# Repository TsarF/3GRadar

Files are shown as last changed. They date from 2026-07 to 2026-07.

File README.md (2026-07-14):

# 3GRadar

Antenna design workspace for a **3.1–3.4 GHz** (9% band) radar front end, targeting
manufacture on **JLCPCB PTFE** (ZYF300CA-C, Dk 2.94, Df 0.0016, 1.52 mm). Electromagnetic
design is done with **openEMS** (FDTD) driven from Python, plus some MATLAB Antenna Toolbox
prototyping and a KiCad project for the RF board.

The current focus is a high-gain **Fabry–Perot cavity (FPC) antenna** — a fed patch under a
partially-reflecting surface (PRS) and a resonant complementary metasurface (RCM), inspired
by Ding et al. (*Results in Engineering* 27, 2025), retuned for the 3.25 GHz band.

> Note: the reference paper PDF and all multi-GB openEMS run outputs are intentionally
> excluded from version control (see `.gitignore`).

## Layout

**Fabry–Perot cavity antenna (active work)**
- `fpc3_build.py` — 3-layer model: inset-fed patch → air cavity → wire-grid PRS → air cavity → subdivided RCM. Env/flag-configurable (`FEED_ONLY`, `RCM_ON`, `MATCH_ON`, …).
- `fpc3_optimize_de_gain.py` — differential-evolution optimizer maximizing **worst-in-band realized gain**, co-tuning feed (y0, L, W) with cavity (h_cav, h3) and RCM sub-spacing (rcm_gap). Full-state checkpointing (resumes after interruption); parallelism is env-configurable.
- `fpc3_validate.py` — high-fidelity full-cavity validation (S11, input Z, directivity, realized gain).
- `fpc3_characterize.py`, `fpc3_impedance.py`, `fpc3_feed_optimize.py`, `fpc3_sweep.py` — diagnostics and feed studies.
- `fpc2_*.py`, `fpc_*.py` — earlier single-PRS and first-cut FPC iterations.
- `fpc_bempp_*.py` — MoM/BEM cross-checks via `bempp-cl`.

**Guides**
- `fpc3_THREADRIPPER.md` — running the optimizer on a many-core box (worker/thread sizing).
- `fpc3_EC2.md` — running it on EC2 M8g **spot** with checkpoint durability (S3 sync / persistent EBS).

**Other antenna studies**
- `inset_slot_*.py`, `inset_patch_build.py`, `series_patch_build.py` — patch feed studies.
- `pcb_*.py`, `array2x2_build.py` — 2×2 PCB array build/optimize.
- `*.m` — MATLAB horn, patch, and matching-network prototyping.

**Board**
- `3GRadar.kicad_*`, `TX.kicad_sch`, `RX.kicad_sch`, `Parts.pretty/` — KiCad RF project.

## Requirements
Python with `openEMS` + `CSXCAD` bindings, `numpy`, `matplotlib` (and `bempp-cl` for the MoM
cross-checks). openEMS must be built for your platform (no ARM64 wheels — see `fpc3_EC2.md`).

## Optimizer quick start
```bash
python fpc3_optimize_de_gain.py                 # local defaults (2 workers x 4 threads)
FPC_WORKERS=16 FPC_THREADS=4 FPC_TAG=_run python fpc3_optimize_de_gain.py   # bigger box
```
It checkpoints the best design to `fpc3_gain_de_opt<TAG>/optimized_params.json` and the full
DE state to `de_state.pkl`; relaunching resumes mid-search.

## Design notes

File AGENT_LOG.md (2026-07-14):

# AGENT_LOG — Autonomous FPC antenna iteration

Agent: Claude (Opus 4.8). Objective: push worst-in-band realized boresight gain
toward ~15 dBi over 3.1–3.4 GHz within a ≤200 mm board. All gain numbers reported
to the user MUST come from FDTD; bempp is trend-screening only.

---

## 2026-07-07 ~16:40 PDT — Takeover / initial status

**Read HANDOFF.md in full.** Understood mission, solvers, gotchas, guardrails.

**Process health (both alive, verified with Get-Process):**
- DE optimizer `fpc3_optimize_de_gain.py` — PID 8928 (python, started 16:22).
- Watchdog `fpc3_watchdog.ps1` — PID 37168 (powershell, started 16:26).
  Heartbeat `watchdog.hb` current (16:36).
- Did NOT start a second optimizer (per guardrail).

**DE state:** freshly started. `optimized_params.json` does NOT exist yet — still on
the initial population (16 members, NP=16), 0 evals logged in `optimization_log.csv`.
Two FDTD workers running (worker_42740 @~17 min, worker_45436 @~17 min), both ringing
down normally (high-Q cavity; energy decaying past -8 dB). Coarse opt mesh (~4M cells),
WORKERS=2 × 4 threads. Objective = worst-in-band realized gain over 3.10–3.40 GHz;
knobs h_cav[42–50], rcm_s[13–20], h3[36–50], y0[5–13]. Converges on stagnation
(3 gens no improvement) or GEN_CAP=100 / MAX_EVALS=600.

**Timeline estimate:** initial population of 16 at ~20–30 min/eval, 2 at a time
≈ 8 batches ≈ 3–4 h just for gen 0, then DE generations. This is a multi-hour/overnight
run. Plan: poll status + logs periodically, do NOT block.

**Machine:** AMD Ryzen 7 5800X3D, 8 cores / 16 logical, 32 GB RAM (10.6 GB free with
the 2 FDTD workers using ~21 GB). Headroom exists for a thread-limited bempp screen.

**Baseline (pre-DE, from HANDOFF):** hand-swept best D=14.5 dBi, realized-gain peak
12.7 dBi at h_cav=45, rcm_s=17, h3=45, y0=9.5. Known weakness: RCM peak is narrow
(single resonance) — gain sags at band edges → worst-in-band is the limiter.

**Plan:**
1. Let the DE run to convergence; validate winner with `fpc3_characterize.py` (fine mesh).
2. In parallel (thread-limited so as not to starve FDTD): bempp-screen the multi-size /
   weaker RCM idea to see if a second resonance flattens the band. bempp = direction only.
3. Only commit FDTD time to bempp-validated directions.

## 2026-07-07 ~16:55 PDT — bempp import OK; multi-size RCM screen launched

- Confirmed bempp_cl 0.4.2 imports (9 s, 2 threads). DE workers healthy: worker_45436
  at -11.5 dB ringdown (TS 34.6k/70k), worker_42740 at -5 dB (TS 30k). Ringdown is slow
  → revised eval estimate ~35–45 min each, so gen 0 (16 evals ÷ 2) ≈ ~5 h.
- Wrote `fpc_bempp_rcm_screen.py` (new): screens the TOP improvement idea from HANDOFF
  §6 — does a MULTI-SIZE RCM (3 interleaved square sizes {14.5,17,19.5} by (i+j)%3,
  PEC-in-air) sag LESS at band edges than a UNIFORM RCM? Runs one process per frequency
  (3.10/3.25/3.40 GHz) so numba compiles k fresh each time. Syntax-checked; fpc3_build
  also syntax-checked (still buildable).
- Launched it in the background at 2 threads (OMP/MKL/NUMBA/OPENBLAS=2) so it does NOT
  starve the priority-1 DE (8-core CPU already saturated by 2×4-thread FDTD). Output →
  `scratch_bempp_rcm_screen.out`. This is SCREENING ONLY (direction, not magnitude).
  Will monitor DE MC/s; if it collapses I kill the screen.

## 2026-07-07 ~17:15 PDT — Restructured bempp screen to ONE process; DE healthy

- Coordinator guidance: bempp's first solve per PROCESS pays a one-time numba/OpenCL
  compile; run the whole variant sweep in ONE process to amortize it. My first version
  was one-process-per-frequency (3 compiles) and its first solve was very slow under
  2-thread contention (only the 3.10 GHz header printed after ~15 min).
- Killed the old screen SURGICALLY (only the python whose cmdline matched
  `fpc_bempp_rcm_screen`; PID 42228) and stopped the driver loop. Verified DE optimizer
  PID 8928 + its two workers (45436, 42740) and watchdog 37168 all still alive.
- DE health throughout: workers held ~98-103 MC/s (no starvation from 2-thread bempp).
  worker_45436 reached -17 dB ringdown (TS 49k/70k) ~28 min in — first evals ~30-40 min.
  Still 0 rows in optimization_log.csv (gen 0 not finished).
- Rewrote `fpc_bempp_rcm_screen.py`: single process, FREQS(3.10/3.25/3.40) outer x
  variants(no-RCM / uniform s=17 / multi{14.5,17,19.5} interleaved) inner. Per-freq RHS
  via `make_rhs(kval)` closure factory (numba freezes k at compile, so a fresh fn per
  freq is needed). Prints a broadside-D-vs-freq trend table + sag(max-min). Syntax OK.
  Relaunched at 2 threads -> `scratch_bempp_rcm_screen.out` (bg task bgsenqhfi).
- Set up a persistent monitor on driver.out/err + watchdog.log for DE milestones
  (task bvfzcac6x): fires on NEW BEST / gen-done / Converged / generation cap /
  BEST 3-layer / Traceback / watchdog restart / WATCHDOG_DONE.

## 2026-07-07 ~17:20 PDT — Validation procedure prepared (read characterize + watchdog)

Read fpc3_characterize.py, fpc3_watchdog.ps1, fpc3_status.py. Key facts for when the
DE converges:
- `fpc3_characterize.py` imports `fpc3_build as p1` and uses its MODULE-LEVEL knobs
  (h_cav, rcm_s, h3, y0 via `_recompute`). It does NOT read optimized_params.json.
  It uses the FINE mesh (fpc3_build mesh_res = .../24) and NrTS=120000, EndCriteria
  1e-4, NFREQ=601, NGAIN=21, THREADS=8. Output -> fpc3_char/openems.log, plots +
  char_data.npz. ~1 hr. `--replot` reuses char_data.npz.
- Watchdog checks the "done" tail (BEST 3-layer DESIGN | Converged (population |
  generation cap) BEFORE the alive-check each 300 s loop, so on clean convergence it
  writes WATCHDOG_DONE and breaks with NO spurious relaunch. => after convergence the
  optimizer process has exited and nothing heavy is running -> safe to run characterize
  (respects "never two heavy FDTD at once").

VALIDATION PLAN (execute on the convergence milestone):
  1. Confirm optimizer PID 8928 exited + WATCHDOG_DONE present (or driver.out shows
     BEST 3-layer). `python fpc3_status.py` to read winner params.
  2. Set winner h_cav/rcm_s/h3/y0 into fpc3_build.py defaults (small, reversible edit;
     harmless to any watchdog relaunch since the DE warm-starts from the JSON, not the
     module defaults). Syntax-check + 3x3 smoke build first.
  3. Launch `python fpc3_characterize.py` detached; poll fpc3_char/openems.log.
  4. Record real worst-in-band S11 + realized gain-vs-freq (this is the FDTD number to
     report to the user).

Now yielding to armed notifications (bempp screen bgsenqhfi completion + DE milestones
bvfzcac6x). Not polling blindly per coordinator guidance.

## 2026-07-08 ~09:26 PDT — Re-engaged (overnight); DE MILESTONE + bempp relaunch

Was dormant overnight — the persistent monitor did NOT reliably wake me (its events
arrived only when I re-engaged). LESSON: treat resumption as self-paced, not
event-driven. Will note a next-action time before each yield.

**DE MILESTONE (verified via fpc3_status.py):** 50 evals, gen 3.
  BEST worst-in-band realized gain = **11.84 dBi**
  params: h_cav=45.5, rcm_s=17.5, h3=49.5, y0=6.6  (fixed L=26.5,W=29.4,sb=16,N=9,P=21.5)
  across band [3.10..3.40] = [12.47, 13.34, 11.84, 11.97, 11.88] dBi  (found at eval 48)
  NEW BEST progression: e1 +6.41 -> e4 +6.56 -> e5 +10.80 -> e35 +11.55 -> e47 +11.84.
  This is a FLAT band (spread ~1.5 dB, worst 11.84) vs the narrow-peak hand baseline
  (D=14.5 / realized peak 12.7 but sagging hard at edges -> low worst-in-band). The DE
  is optimizing exactly the right thing (worst-in-band) and has traded peak for
  flatness. h3=49.5 sits near the top of its [36,50] range and rcm_s=17.5 mid — worth
  noting h3 may want to exceed 50 (bound may be limiting; revisit after convergence).
  DE STILL RUNNING (2 FDTD workers, ~95 MC/s) -> NOT running characterize yet (guardrail).

**bempp screen had DIED** (bg bash task got killed when I went dormant) after ONE data
  point: no-RCM @3.10 GHz -> broadside 6.69 dBi, peak 8.27@38deg, DOF 5743, and that
  single solve took **837 s** (~14 min) under 2-thread contention. Full 3-freq x 3-var
  screen ~= 2 h. RELAUNCHED robustly as a detached hidden OS process via PowerShell
  Start-Process (PID 46968, pidfile bempp_screen.pid, env OMP/MKL/NUMBA/OPENBLAS=2),
  stdout->scratch_bempp_rcm_screen.out, stderr->.err. Verified alive; it is computing
  the 3.10 GHz no-RCM solve now. DE workers still ~95 MC/s alongside it (not starved).

NEXT ACTION (self-paced): check back ~10:15 PDT to confirm the bempp screen passed the
first point (no-RCM@3.10) and ideally has uniform-vs-multi numbers; and re-poll DE
status. Waiting on: (a) bempp screen verdict on multi-size RCM, (b) DE convergence to
trigger FDTD validation of the flat-band winner.

## 2026-07-08 — COORDINATOR NOTE (main): widened h3 bound + restarted DE
Acted on your finding that h3 was pinned at its upper bound (49.5/50) in the 11.84 dBi
best -> the bound was throttling the DE. Edited fpc3_optimize_de_gain.py PARAMS: h3
upper 50 -> 58. Killed old DE (PID 8928 + workers), relaunched cleanly (NEW PID 1440,
driver.pid updated), warm-started from optimized_params.json so the 11.84 flat-band best
is preserved as the seed. New DE now explores h3 up to 58. Watchdog unaffected (reads
driver.pid=1440). On your next self-resume: fpc3_status.py reflects the new PID; keep
monitoring for a new best above 11.84 that uses h3>50, and proceed with your validation
plan on convergence.

## 2026-07-08 — COORDINATOR NOTE (main): match is the bottleneck; added L,W knobs
Read the best design's S11 (live_s11.png): dips only to ~-4.8 dB @3.13 GHz, worst-in-band
~-1.9 dB, NEVER below -10 dB. Yet realized gain is ~12 dBi flat => directivity is
~16-17 dBi (aperture ceiling) and the POOR MATCH is throwing away ~4 dB. So directivity
is maxed; the FEED MATCH is now the bottleneck. Added L[24.5-28.5], W[26.0-33.0] to the
DE knobs (was only y0 for match) so it can center/deepen the S11 dip. Restarted DE:
NEW PID 52208, 6 knobs [h_cav,rcm_s,h3,y0,L,W], warm-started from optimized_params.json
(the 11.84 best). driver.pid updated. Watch for a new best where S11 goes <-10 and
realized gain climbs toward ~15-16. When you validate at convergence, report the S11
too (it's the story).

## 2026-07-09 ~14:45 PDT — NEW FOCUSED TASK: matched-feed design (DE PAUSED)

Coordinator paused DE + watchdog (DE_PAUSED marker 2026-07-09T14:42) so I have the full
8 cores for FDTD. Do NOT relaunch the DE. Best (11.84 dBi) checkpointed & safe. On
re-engage all processes were already stopped. Stopped the stale milestone monitor
bvfzcac6x. Dropped the multi-size bempp screen (moot now; bempp can't model feed Z).

Best design to match (optimized_params.json): h_cav=45.5, rcm_s=17.5, h3=49.5, y0=6.6,
L=26.5, W=29.4. Directivity ~16-17 dBi (aperture ceiling) but S11 only ~-5 dB (never
< -10) -> ~4 dB of realized gain lost. Cavity/RCM maxed; pure feed-impedance problem.

Feed geometry (fpc3_build): inset-fed patch, 50-ohm microstrip feed line Wf=3.89
(≈50 ohm on 1.52mm PTFE eps_r=2.94) from port x_port=-23.25 to x_in=-6.65 (inset depth
y0=6.6, gap g=1.0, Lf=10). Port = z-lumped 50 ohm at outer feed-line end. DE swept y0
(and L,W) but couldn't beat -5 dB => an impedance offset the inset can't null (cavity
detunes feed, gotcha #4). Plan: diagnose Z(f) then add a quarter-wave transformer /
reference-plane shift / stub in the FEED LINE ONLY.

STEP 1: launched `python fpc3_impedance.py` (moderate mesh /22, NRTS 90k, 8 threads)
detached -> stdout fpc3_impedance/run_stdout.log, FDTD fpc3_impedance/openems.log.
Polling. ~30-45 min.

Impedance FDTD verified running cleanly at ~190 MC/s (8 threads, full machine; DE paused).
While it runs, prepared a matching-network calculator (scratchpad/match_design.py):
reads impedance.csv, diagnoses Z at 3.10/3.25/3.40 + min-S11 + X=0 crossings, and
synthesizes microstrip dims on PTFE (eps_r=2.94, h=1.52). Validated: 50 ohm -> W=3.906 mm
(design Wf=3.89 = 50.14 ohm, confirms feed line is 50 ohm); lg/4 ~= 15 mm @3.25 GHz.
Quarter-wave transformer ready: Zt=sqrt(50*R), e.g. R=100->Zt=70.7ohm W~2.2mm,
R=25->Zt=35ohm W~6mm. NEXT: read Z when the run finishes, diagnose, design, implement.

## 2026-07-09 ~15:40 PDT — IMPEDANCE DIAGNOSIS + narrowband match designed & implemented

Baseline impedance run done (2570 s). Full picture (moderate mesh /22):
  f(GHz)  D(dBi)   Z = R + jX (ohm)      S11
  3.10    11.42    4.4  -5.1            -1.52   <- series resonance (X=0), R tiny
  3.25    15.92    38.2 +79.6           -3.38   <- band center, R near 50 but big +X
  3.30    16.39    81.5 +142.8
  3.35    16.45    264.6 +177.4          (peak D)
  3.395   ~16.2    ~365 +0              anti-resonance (X=0), R huge
  3.40    16.02    365.4 -18.4
  Directivity rises MONOTONICALLY toward the cavity anti-resonance (~3.40). In-band R
  swings 4.4 -> 365 ohm (~80x), X up to +191. |Gamma|~0.68 even at the best in-band point
  => broadband match is Bode-Fano IMPOSSIBLE (confirms coordinator). Baseline files saved
  as fpc3_impedance/impedance_baseline.{csv,png}, imp_baseline.npz.

DESIGN FREQ = 3.25 GHz (band center). Chosen over the higher-D points because R=38 is
already closest to 50 (only reactance to null) and D=15.92 is just 0.5 dB below the peak
(16.45), with more usable bandwidth than the extreme anti-resonance (3.395, R=365).

MATCH (offset line + quarter-wave transformer, all-microstrip, no stub/T-junction):
  Load at old port @3.25: Z_L=38+j80, |Gamma|=0.677 @ +56.4 deg.
  1. Extend the 50-ohm feed line OUTWARD by Loff=4.68 mm (reference-plane shift; rotates
     Gamma to the +real axis -> Z=260 ohm real).
  2. Quarter-wave transformer Zt=sqrt(50*260)=114 ohm -> W=0.75 mm, length Lt=15.68 mm
     (lambda_g/4 @3.25). Transforms 260 -> 50 ohm. New port at outer end (x=-43.6 mm).
  Prepended OUTWARD from the old port so the patch/inset/cavity/RCM are untouched and the
  inward load (38+j80) is preserved automatically. Dims from scratchpad/match_design.py.

IMPLEMENTED in fpc3_build.py behind MATCH_ON toggle (default True):
  - new params Loff=4.68, Wt=0.75, Lt=15.68; _recompute now computes x_port (extended
    feed-line end) and x_tr_out (new port); feed_x=x_tr_out when matching.
  - build_antenna adds the transformer box (x_tr_out..x_port, width Wt) + mesh lines at
    x_port/x_tr_out and y=+/-Wt/2. Syntax OK. 3x3 smoke build meshes cleanly. New port
    x=-43.6 is well inside the 9x9 board (+/-96.75 mm).
  - MATCH_ON=False reverts to the original single-port feed (reversible).

VALIDATION: launched fpc3_impedance.py with the matched feed (bg bu30a64tw), ~185 MC/s,
~40 min. Baseline outputs preserved; new run overwrites impedance.{csv,png}/imp_data.npz
= the MATCHED result. Will read S11(3.25), the -10 dB bandwidth, realized gain, and
confirm directivity held. Next self-resume ~16:25 PDT (or on task completion).

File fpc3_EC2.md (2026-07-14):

# Running the FPC co-optimizer on EC2 M8g spot

`fpc3_optimize_de_gain.py` now writes a **full DE-state checkpoint** (population, per-member
costs, generation, RNG state, eval cache, best, history) atomically after *every* eval, and
resumes from it on launch. So a spot reclaim costs at most the few evals in flight — they
re-run as cache-hits. Validated: interrupt → relaunch → `>>> RESUMED ... gen=N` and continue.

## Region
Best **M8g spot price + capacity**: **us-east-2 (Ohio)** or **us-east-1 (N. Virginia)** —
deepest Graviton capacity and typically the cheapest spot. `us-west-2` / `eu-west-1` are
fine alternates. This is a batch job, so latency to you is irrelevant — optimize for price
and interruption rate. Before launching, check **EC2 Console → Spot Requests → Spot
placement score** for `m8g.16xlarge` in your candidate regions/AZs and pick the highest.

## Instance size — match it to the DE, not "biggest"
DE is synchronous: within a generation only **NP** trials can run in parallel (default
`NP=16`). Beyond 16 concurrent evals there's nothing to run until the generation closes. So
the sweet spot evaluates one whole generation at once:

**→ `m8g.16xlarge` (64 vCPU, 256 GiB): `FPC_WORKERS=16 FPC_THREADS=4`.**
One generation = one parallel batch ≈ one eval-time. Graviton4 is 1 vCPU = 1 real core (no
SMT) with DDR5-5600, so 64 vCPU = 64 real cores and the numbers are honest. RAM is a
non-issue (~6.9 M cells ≈ ~2 GB/worker → ~32 GB of 256).

- Want more exploration? `FPC_NP=24` on **`m8g.24xlarge`** (96 vCPU) → `FPC_WORKERS=24 FPC_THREADS=4`.
- **Don't** jump to `m8g.48xlarge` (192 vCPU) with NP=16 — 176 vCPU sit idle. Only worth it
  if you raise NP to ~48 (slower per-gen, more thorough) or run multiple islands.
- openEMS is memory-bandwidth bound; if a single eval is slow, try `FPC_THREADS=4` vs `8`
  with correspondingly fewer workers and keep whichever gives more **evals/hour** (the
  benchmark loop in `fpc3_THREADRIPPER.md` §3 works here too).

## Setup (ARM64 / aarch64)
The AMI must be ARM64 (Amazon Linux 2023 arm64 or Ubuntu 24.04 arm64). openEMS has no ARM
wheels — build once from source and bake an AMI so respawns are instant:
```bash
sudo dnf groupinstall -y "Development Tools" || sudo apt-get install -y build-essential
# deps: cmake, boost, hdf5, CGAL, tinyxml, vtk, qt; then build openEMS + python bindings
#   https://docs.openems.de/install/  (build AppCSXCAD/CSXCAD/openEMS, pip install its python/)
python -c "import fpc3_build, openEMS, CSXCAD; print('ok')"   # must pass
```
Bake this into a custom AMI so a reclaimed-then-relaunched spot boots ready.

## Spot fault tolerance — durable checkpoint
The checkpoint file must **survive instance termination**. Two options:

**A) S3 sync (recommended — survives full instance loss).** Give the instance an IAM role
with access to a bucket, then run a background sync alongside the optimizer:
```bash
export FPC_CKPT=/data/fpc/de_state.pkl        # local path the optimizer writes
mkdir -p /data/fpc
aws s3 cp s3://YOUR_BUCKET/fpc/de_state.pkl "$FPC_CKPT" 2>/dev/null || true   # restore if exists
# push checkpoint + best to S3 every 60s in the background:
( while true; do
    aws s3 cp "$FPC_CKPT" s3://YOUR_BUCKET/fpc/de_state.pkl --only-show-errors || true
    aws s3 cp fpc3_gain_de_opt_EC2/optimized_params.json s3://YOUR_BUCKET/fpc/ --only-show-errors || true
    sleep 60
  done ) &
```
On a fresh instance the `aws s3 cp ... "$FPC_CKPT"` restore line pulls the latest state and
the optimizer resumes. (Checkpoint is <1 MB, so 60 s sync is cheap. Optionally also trigger
a sync on the 2-min interruption notice — poll
`http://169.254.169.254/latest/meta-data/spot/instance-action`.)

**B) Persistent EBS.** Put the repo + `FPC_CKPT` on a data EBS volume with
`DeleteOnTermination=false`; after a reclaim, launch a new spot, attach the volume, relaunch.

**Auto-relaunch:** request a **persistent** spot request (not one-time) with interruption
behavior `stop` or `terminate`; it re-provisions when capacity returns. Put the launch
command (below) in user-data so a respawn restores from S3 and continues unattended.

## Launch (detached, resumable)
```bash
cd /path/to/3GRadar
# seed the island from your current global best (first launch only):
mkdir -p fpc3_gain_de_opt_EC2
aws s3 cp s3://YOUR_BUCKET/fpc/optimized_params.json fpc3_gain_de_opt_EC2/ 2>/dev/null \
  || cp fpc3_gain_de_opt/optimized_params.json fpc3_gain_de_opt_EC2/ 2>/dev/null || true

FPC_WORKERS=16 FPC_THREADS=4 FPC_TAG=_EC2 FPC_SEED=2025 \
FPC_CKPT=/data/fpc/de_state.pkl \
  nohup python fpc3_optimize_de_gain.py > fpc3_gain_de_opt_EC2/driver.out 2>&1 &
echo $! > fpc3_gain_de_opt_EC2/driver.pid
tail -f fpc3_gain_de_opt_EC2/driver.out
```
If reclaimed and relaunched with the **same env**, it prints `>>> RESUMED ... gen=N` and
continues. `FPC_TAG=_EC2` keeps it isolated from the local run so nothing clobbers.

## Cost sanity
`m8g.16xlarge` on-demand ≈ small-single-digit $/hr; spot typically ~60-70% off. If the
search needs ~20 generations and a generation ≈ one eval-time, budget by benchmarking one
eval on the instance first (`evals/hour` loop) — you'll know $/run before committing.

## Take the winner back
Copy `fpc3_gain_de_opt_EC2/optimized_params.json` (or the S3 copy) into the repo, compare
`worst_realized_gain_dBi` against the local/TR bests, set the winner into `fpc3_build.py`,
and validate at full fidelity: `python fpc3_validate.py`.
```

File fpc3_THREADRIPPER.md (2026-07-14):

# Running the FPC co-optimizer on the Threadripper 7960X

The optimizer (`fpc3_optimize_de_gain.py`) is one script, env-configurable. On the big box
you run it as an **independent island**: its own output dir (`FPC_TAG=_TR`), warm-started
from the current global best, a different `FPC_SEED` so it explores different trials. Both
machines use the *same geometry + mesh (/16)*, so the two `optimized_params.json` are
directly comparable — at the end you keep whichever design has the higher worst-in-band
realized gain. The local run is untouched (defaults preserve 2 workers × 4 threads).

## Why these worker/thread numbers
openEMS FDTD is **memory-bandwidth bound** — a single sim stops scaling past ~6-8 threads.
Throughput on many cores comes from running **more parallel workers**, not fatter sims.
The 7960X has 24 cores across **4 CCDs of 6 cores** (quad-channel DDR5). So:

| Config | env | notes |
|---|---|---|
| **4×6 (start here)**| `FPC_WORKERS=4 FPC_THREADS=6` | one worker per CCD — cache/NUMA-local |
| 6×4 | `FPC_WORKERS=6 FPC_THREADS=4` | more parallel evals, crosses CCDs  |
| 8×3 | `FPC_WORKERS=8 FPC_THREADS=3` | max parallelism; may saturate DRAM BW |

RAM: ~6.9 M cells/worker ≈ ~2 GB/worker → even 8 workers ≈ 16 GB. Not the limiter.
**Benchmark before committing** (see below) — pick the config with the best *evals/hour*,
which is workers ÷ median-eval-time, not just the most workers.

## 1. Get the repo + deps on the TR
Copy the whole `3GRadar` folder over **including** `fpc3_gain_de_opt/optimized_params.json`
(that's the seed). Install openEMS with Python bindings (`openEMS`, `CSXCAD` importable),
plus `numpy`, `matplotlib`.

Quick check the model builds there:
```bash
python -c "import fpc3_build, openEMS, CSXCAD; print('ok')"
```

## 2. Seed the island from the current global best
```bash
# Linux/macOS
mkdir -p fpc3_gain_de_opt_TR
cp fpc3_gain_de_opt/optimized_params.json fpc3_gain_de_opt_TR/optimized_params.json
```
```powershell
# Windows PowerShell
New-Item -ItemType Directory -Force fpc3_gain_de_opt_TR | Out-Null
Copy-Item fpc3_gain_de_opt\optimized_params.json fpc3_gain_de_opt_TR\optimized_params.json
```
(Alternatively skip the copy and point `FPC_WARM` at the local best directly.)

## 3. Benchmark one eval per config (optional, ~15 min, recommended)
Times a single full-cavity eval so you can compare evals/hour:
```bash
for W in "4 6" "6 4" "8 3"; do set -- $W; \
  echo "=== $1 workers x $2 threads ==="; \
  FPC_WORKERS=$1 FPC_THREADS=$2 FPC_TAG=_bench FPC_NP=$1 python - <<'PY'
import os,time,fpc3_optimize_de_gain as o
from concurrent.futures import ProcessPoolExecutor
x=o.snap(o.np.array([o.PARAMS[n][0] for n in o.names]))
t=time.time()
with ProcessPoolExecutor(max_workers=o.WORKERS) as ex:
    list(ex.map(o.eval_worker,[(x,os.path.join(o.sim_path,'b%d'%i),o.THREADS_PER_WORKER) for i in range(o.WORKERS)]))
dt=time.time()-t
print("  %d evals in %.0fs -> %.1f evals/hour"%(o.WORKERS,dt,o.WORKERS*3600/dt))
PY
done; rm -rf fpc3_gain_de_opt_bench
```
Keep the config with the highest evals/hour.

## 4. Launch the island (detached)
```bash
# Linux/macOS — replace 4 6 with your benchmark winner
FPC_WORKERS=4 FPC_THREADS=6 FPC_TAG=_TR FPC_SEED=777 \
  nohup python fpc3_optimize_de_gain.py > fpc3_gain_de_opt_TR/driver.out 2>&1 &
echo $! > fpc3_gain_de_opt_TR/driver.pid
```
```powershell
# Windows PowerShell
$env:FPC_WORKERS=4; $env:FPC_THREADS=6; $env:FPC_TAG='_TR'; $env:FPC_SEED=777
$p = Start-Process python 'fpc3_optimize_de_gain.py' -WindowStyle Hidden -PassThru `
  -RedirectStandardOutput fpc3_gain_de_opt_TR\driver.out -RedirectStandardError fpc3_gain_de_opt_TR\driver.err
$p.Id | Out-File -Encoding utf8 fpc3_gain_de_opt_TR\driver.pid
```

Watch progress:
```bash
tail -f fpc3_gain_de_opt_TR/driver.out          # new-bests + gen summaries
cat  fpc3_gain_de_opt_TR/optimized_params.json  # current best (checkpointed live)
```

## 5. Take the winner back
When done (or when you return the TR), copy `fpc3_gain_de_opt_TR/optimized_params.json`
back into the repo. Compare `worst_realized_gain_dBi` between it and the local
`fpc3_gain_de_opt/optimized_params.json`; set the better design's params into
`fpc3_build.py` and validate at full fidelity with `python fpc3_validate.py`.

**Crash-safe:** the island checkpoints its best every improvement and warm-starts from it,
so if the process dies just relaunch step 4 — no progress lost.

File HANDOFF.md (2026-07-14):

# Antenna Design — Autonomous Handoff Manifest

You are a Claude instance taking over an antenna-design project to **iterate on it
autonomously**. Read this whole file first. It is your single source of truth.

---

## 1. Mission

Design a **high-gain Fabry–Perot cavity (FPC) antenna** for **3.1–3.4 GHz** (9 %
band) on the JLCPCB **PTFE ZYF300CA-C** stack (Dk 2.94, Df 0.0016, 1.52 mm boards),
board side **≤ ~200 mm**. **Objective: maximize the worst-in-band realized boresight
gain** `G = D_broadside · η_rad · (1 − |S11|²)` over 3.10–3.40 GHz.

Practical ceiling at 194 mm (2.1 λ) aperture is **~15 dBi** (the source paper hit 14.9
at this electrical size). 17 dBi is not physical here without a bigger board.

---

## 2. Current state (READ `python fpc3_status.py` FIRST)

- **Best design so far:** the 3-layer antenna `fpc3_build.py` (feed patch + dual-layer
  PRS + RCM superstrate). Hand-swept best: **D = 14.5 dBi, peak realized gain 12.7 dBi**
  at `h_cav=45, rcm_s=17, h3=45, y0=9.5`.
- **A DE optimizer is ALREADY RUNNING** (`fpc3_optimize_de_gain.py`, detached, PID in
  `fpc3_gain_de_opt/driver.pid`) under a **watchdog** (`fpc3_watchdog.ps1`, PID in
  `watchdog.pid`) that relaunches it if it dies. **Do NOT start a second optimizer** —
  check `fpc3_status.py` and the watchdog first.
- It checkpoints the best to `fpc3_gain_de_opt/optimized_params.json` on every
  improvement and logs every eval to `optimization_log.csv`. Warm-starts from the JSON,
  so nothing is lost across restarts.

---

## 3. Environment & solvers

- **Windows, Python 3.13, NVIDIA RTX 4070.** PowerShell is primary; a bash tool exists.
- **openEMS (FDTD), Python bindings** — the accurate solver (has the dielectric). SLOW
  for this high-Q cavity: ~20–30 min/eval at coarse mesh (`mesh_res /20`, ~4 M cells),
  ~1 hr at fine mesh. **This is the source of truth for final numbers.**
- **bempp-cl (MoM, installed as `bempp_cl`)** — fast (~3 min/solve) but **PEC-in-air**
  (ignores the PTFE), so it **undershoots absolute gain by ~3 dB and its optimum spacings
  are ~0.83× the FDTD ones**. CPU only (GPU gives NO speedup — measured). **Use bempp
  ONLY to screen trends/direction cheaply, then validate in FDTD.**
- openEMS output is fd-redirected to per-run logs so it doesn't spam stdout.

---

## 4. File inventory

Active FPC design (use these):
- `fpc3_build.py` — the 3-layer antenna. Knobs: `h_cav, rcm_s, h3, y0` (+ fixed
  `L=26.5, W=29.4, sb=16, r1=6.5, pb=20.7, P=21.5, N_PRS=9`). `RCM_ON` toggles the RCM.
- `fpc3_optimize_de_gain.py` — the running DE (objective = worst-in-band realized gain).
- `fpc3_characterize.py` — full validation: S11 + gain-vs-freq + directivity + E/H
  patterns. `--replot` reuses saved data. ~1 hr (fine mesh).
- `fpc3_sweep.py` — lean N-point FDTD sweep (edit `POINTS`), coarse mesh.
- `fpc3_watchdog.ps1` — keeps the optimizer alive.
- `fpc3_status.py` — one-shot status.
- `fpc_bempp_directivity.py` — bempp MoM directivity screen (edit the sweep in `main()`).

Baselines / building blocks:
- `fpc2_build.py`, `fpc2_characterize.py` — single-PRS FPC (~11 dBi, matched). `FEED_ONLY`
  flag builds just the bare patch.
- `fpc2_prs_unitcell.py` — dual-layer PRS reflection extractor (|Γ|, phase, Trentini
  cavity height) via a TEM waveguide unit cell.
- `fpc2_feed_optimize.py` — Stage-A bare-patch match optimizer (fast, feed-only).
- Older experiments (context only): `fpc_build.py`, `series_patch_build.py`,
  `inset_slot_*`, `inset_patch_*`, `pcb_*`, `part2_simulate.py`.
- `fpc_metasurface paper.pdf` — the source paper (Ding et al., Results in Eng. 27
  (2025) 106647). 3-layer metasurface FPC at 7 GHz; we scaled ×2.15 to 3.25 GHz and
  dropped the CBM (RCS) layer.

---

## 5. Hard-won facts & gotchas (do not relearn these)

1. **Aperture caps gain:** uniform 9×9 (194 mm) → 17.4 dBi ideal, ~15 realized. Bigger
   board needed for more (11×11 ≈ 236 mm → ~17), but user capped ~200 mm.
2. **openEMS drops zero-height cylinders** as "Unused primitive" → build flat discs with
   `AddPolygon` (see `_disc` in the builds). Never use a degenerate `AddCylinder`.
3. **A bare patch can't match across 9 %** (patch BW ~3 %). Match it at BAND CENTER
   (3.25 GHz); the cavity provides band coverage. (Objective for the *feed alone* is S11
   at f0, NOT worst-in-band.)
4. **Adding a superstrate layer detunes the feed** → must re-tune `y0` (and `h_cav`)
   jointly. The RCM's first naive placement killed the match (S11 ≈ 0).
5. **RCM works:** a uniform square-patch RCM adds **+3–5 dB** broadside at `rcm_s≈17,
   h3≈45` — but it's a **single resonance → narrow band** (gain peaks tall, sags at band
   edges). The paper uses THREE varied square sizes to get bandwidth; we haven't.
6. **High-Q ⇒ slow FDTD** (long ringdown). Use `WORKERS=2` (4 thrashes RAM), coarse mesh
   for optimization, fine mesh only for final validation.
7. **bempp PEC-in-air is qualitative only** — screens direction, not magnitude. Its
   optimum ≠ FDTD's. Confirmed it undershoots (single-PRS: bempp 8 vs FDTD 11 dBi).
8. **DE loop bug (fixed):** the loop must terminate on stagnation + a generation cap,
   else it spins forever once the population caches out. Preserve this in any new DE.

---

## 6. Your objective & how to iterate

**Goal:** push worst-in-band realized gain as high as possible (target ~15 dBi) within
≤200 mm, keeping a usable in-band gain floor (not just a tall narrow peak).

**Loop:**
1. `python fpc3_status.py` — see best-so-far, eval count, process health.
2. Verify the optimizer + watchdog are alive (`Get-Process -Id <pid>`). If dead and not
   converged, relaunch the optimizer detached (Start-Process, WorkingDirectory the repo,
   `python fpc3_optimize_de_gain.py`, redirect to `fpc3_gain_de_opt/driver.out`/`.err`,
   hidden, PassThru; write new PID to `driver.pid`). It warm-starts — no loss.
3. When the DE converges (driver.out shows "Converged"/"BEST 3-layer"/"generation cap",
   or a `WATCHDOG_DONE` file appears), run `python fpc3_characterize.py` to VALIDATE the
   winner at fine mesh, and record the real S11 + gain-vs-freq.
4. Then pursue the next improvement (below), using **bempp to screen cheaply first**,
   then **1–2 FDTD validation runs** at the bempp-scaled point. Never blind-grid FDTD.
5. Append everything you do/find/decide to `AGENT_LOG.md` (create it) with timestamps.

**Improvement ideas (in rough priority):**
- **Bandwidth (biggest gap):** the RCM peak is narrow. Try (a) a *weaker* RCM (smaller
  `rcm_s` / bigger `sb`) trading peak for a flatter band, and/or (b) a **multi-size RCM**
  (two or three square sizes per super-cell, like the paper) to add a second resonance
  and flatten gain across 3.1–3.4. This likely needs a new `rcm` build variant.
- **Joint feed re-match** with the RCM present (`y0`, maybe `L`) so realized gain isn't
  killed by mismatch at band edges.
- **PRS reflectivity** (`sb`, `r1`) re-tune for the compound two-layer cavity.
- If the user later relaxes the size cap: 11×11 (236 mm) → ~17 dBi ceiling.

---

## 7. Guardrails (respect these)

- **Never run `WORKERS > 2`** and **never run two heavy FDTD jobs at once** (RAM). One
  optimizer + at most one manual FDTD run.
- **Never delete** `fpc3_gain_de_opt/optimized_params.json` or `optimization_log.csv`.
- **bempp = screening only.** Any gain number you report to the user must come from FDTD.
- Keep the board ≤ ~200 mm and the stack PTFE (Dk 2.94) unless the user says otherwise.
- Checkpoint/log continuously. Prefer small, reversible changes; keep `fpc3_build.py`
  buildable at all times (syntax-check + a 3×3 smoke build before any long run).
- Don't fabricate progress. If a run fails or is inconclusive, say so in `AGENT_LOG.md`.

---

## 8. Quick commands

```
python fpc3_status.py                      # status + best-so-far
python fpc3_characterize.py                # full FDTD validation (~1 hr)
python fpc3_characterize.py --replot       # replot last validation
python fpc_bempp_directivity.py            # bempp trend screen (~3 min/point, edit main)
python -c "import ast; ast.parse(open('fpc3_build.py').read())"   # syntax check
```

Best design lives in `fpc3_gain_de_opt/optimized_params.json`. When in doubt, prefer
watching the running DE to converge over starting new work.

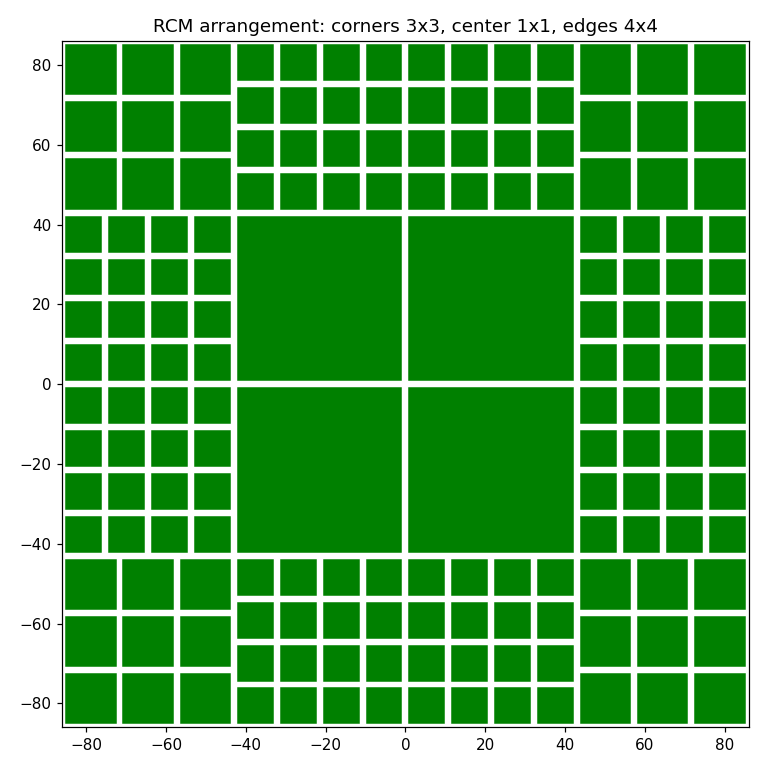
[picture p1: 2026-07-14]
rcm_topview.png

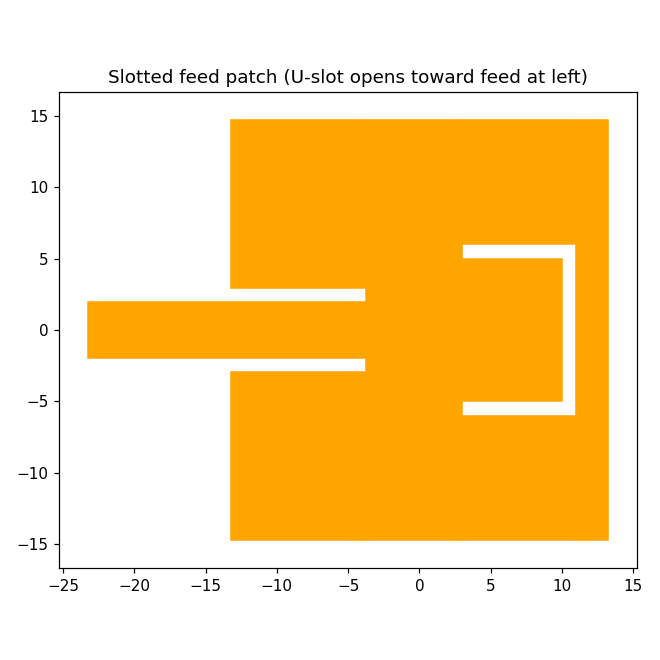
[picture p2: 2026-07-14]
feed_slot_topview.png

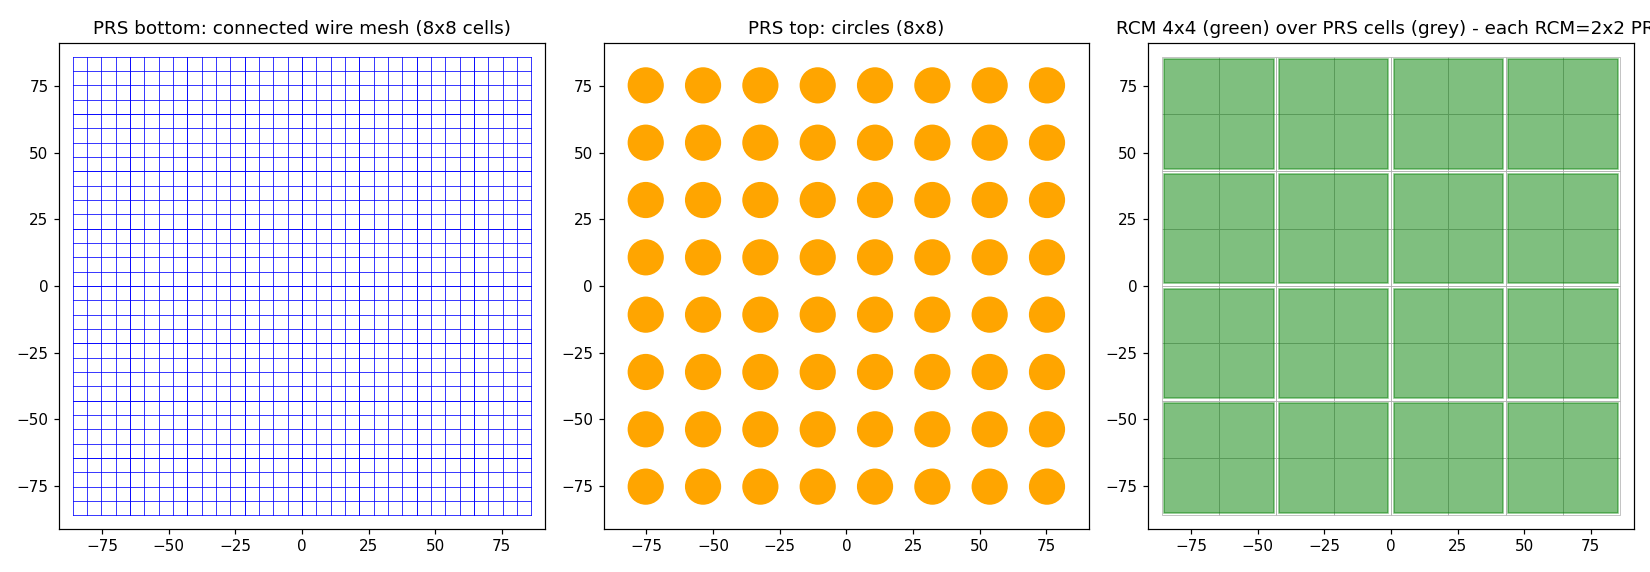
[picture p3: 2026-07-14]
geometry_topview.png

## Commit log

2026-07-14 Initial commit: 3.1-3.4 GHz radar antenna design workspace
    openEMS/Python + MATLAB antenna design for a 3.1-3.4 GHz radar front end on
    JLCPCB PTFE, centered on a Fabry-Perot cavity (FPC) antenna with a wire-grid PRS
    and subdivided RCM. Includes the DE realized-gain co-optimizer (checkpointed,
    env-configurable for multi-machine / EC2 spot), validation/diagnostics, earlier
    patch-array iterations, and the KiCad RF project.
    Reference paper PDF and multi-GB openEMS run outputs are excluded via .gitignore.
    [3GRadar.kicad_pcb, 3GRadar.kicad_sch, RX.kicad_sch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]
2026-07-14 Bake current DE best into fpc3_build defaults (warm-start seed)
    Set h_cav=52, h3=51, rcm_gap=5.5, y0=5.0, L=24.5, W=30.8 -- the 6-knob
    feed+cavity realized-gain DE best so far (worst-in-band +9.40 dBi over 3.1-3.4).
    These defaults are the optimizer's warm-start seed when no de_state/JSON exists,
    so a fresh EC2 clone resumes from this design without an SCP of the checkpoint.
2026-07-14 Fix timestep-cap truncation: PML on all sides + raise NRTS to 150k
    ~82% of evals were hitting the 70k NrTS cap without ringing down to the -30 dB
    EndCriteria -- a parallel-plate mode trapped between the big PEC planes reflected
    off the MUR side walls, so domain energy plateaued and S11/gain were computed on
    an unsettled (truncated) record. Switch all 6 boundaries to PML_8 to absorb that
    mode; raise NRTS to 150k as a safety ceiling (most evals now hit EndCriteria near
    ~77k). Add NRTS+bc to the checkpoint signature so stale truncated caches are not
    resumed. Same fix applied to fpc3_validate.py.
2026-07-14 Model copper as finite-conductivity sheets (not PEC)
    Investigating why some evals still hit the 150k NrTS cap short of -30 dB: with
    lossless PEC metal, the air-filled cavity between the big plates has near-infinite
    conductor Q, so high-Q (narrowband) designs ring essentially forever. Good/broadband
    designs already converge (~130k -> -30 dB, verified), but PEC also overestimates
    realized gain. Switch gnd/patch/PRS/RCM to AddConductingSheet (Cu, 5.8e7 S/m, 35 um):
    realistic loss, de-biased gain, and a bounded cavity Q -> faster ring-down. Add
    metal type to the checkpoint signature so stale PEC-fitness caches are not resumed.
2026-07-16 Harden realized-gain objective: dense match + non-convergence guard
    The EC2 run reported ~17 dBi worst-in-band realized gain with a uniformly ~-5 dB
    in-band S11 -- physically impossible, since 17 dBi exceeds the ~16.4 dBi directivity
    ceiling of the 172 mm aperture. Root cause: high-Q designs that don't ring down to
    the -30 dB EndCriteria within the NrTS cap get their NF2FF directivity computed on
    unsettled fields -> inflated (super-directivity artifact), and a bad match doesn't
    show up because gain was only sampled at NGAIN points.
    Two fixes:
    * Objective now uses worst-in-band realized gain on the DENSE |S11| grid (interp
    directivity/eta_rad, dense match term) so it can't be gamed by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
2026-07-16 Add mesh-convergence check (search-mesh fidelity vs speed)
    The 0.083 mm metal-edge cells Courant-limit the timestep to ~2e-13 s (~1200
    steps/RF-period; Nyquist needs ~2), which is why each eval takes ~3 h -- those
    cells are 3-4x finer than the 0.6 mm PRS wire needs. This runs one design at a
    fine TRUTH mesh vs candidate coarse meshes (edge 0.8/1.0/1.2, min_cell 0.15-0.25)
    in parallel and compares worst-in-band realized gain + |S11|. Adopt the coarsest
    mesh within ~0.3 dB of TRUTH as the search fidelity -> ~3-4x faster EC2 search.
2026-07-16 Make mesh-convergence div22 truth optional (FPC_TRUTH=1)
    Default reference is now the current div16/edge0.4 search mesh -- the mesh we're
    deciding whether to coarsen from -- so the run is gated by ~5.6M cells (~2-3 h on
    m8g) instead of the ~12M div22 mesh (~4-8 h). FPC_TRUTH=1 adds div22 back to also
    confirm div16 is itself converged.
2026-07-17 Add soft match penalty + re-enable U-slot as DE knobs
    The realized-gain objective barely punishes a bad match (a -5 dB match costs only
    1.65 dB of gain), so the DE kept landing on high-directivity/bad-match designs, and
    nothing on EC2 got below -8 dB S11. A hard S11<-10 floor would flatten the objective
    (nothing satisfies it yet) and stall the search, so instead:
    * SOFT graded penalty: score = worst-in-band realized gain
    - MATCH_K*max(0, worstS11 - (-10 dB)) [MATCH_K=1]
    Always gives a gradient; switches off once a design crosses -10 dB. Verified on
    the surrogate: the DE drives S11 from -8 to <-10 dB, then maximizes pure gain.
    * Non-convergence penalty moved out of eval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
2026-07-17 Add thread-scaling benchmark (4 vs 8 vs 16 threads per eval)
    Measures openEMS FDTD throughput (MC/s) vs numThreads, run solo, to pick the best
    workers x threads split. FDTD is memory-bandwidth bound so scaling is sublinear;
    the table reports speedup, parallel efficiency, estimated per-eval time, and a naive
    64-vCPU aggregate. Same physics as the search (PML/copper/mesh16/slot). Short fixed
    NRTS with warm-up discarded so only steady-state timestep speed is measured.
2026-07-17 Log eval_worker exceptions instead of swallowing them
    Half the evals on the 16-worker m8g were returning -inf (silent None). A "-inf"
    design (eval 4) reproduces LOCALLY with a fine -16.65 dB match, so the crashes are
    environmental (intermittent, geometry-independent, only under 16-way parallel load)
    -- most likely the instance filling its disk with openEMS field dumps. The except
    clause now writes the traceback + params to failures/fail_<pid>.log so the real
    cause is visible instead of a swallowed None.
2026-07-18 Raise match penalty weight (MATCH_K 1 -> 3, env-configurable)
    Real _v3 run showed MATCH_K=1 too weak: after 113 evals the DE had pushed gain to
    +14.6 dBi but left worst-in-band S11 stuck at ~-2 dB, using a big slot / tall cavity
    (slot_w, h3 pinned at upper bounds) to pump gain instead of matching. With K=1, 1 dB
    of match and 1 dB of gain score equally, and gain is easier to get.
    MATCH_K=3 makes closing the match gap worth ~3x the gain range, so the DE gets matched
    FIRST then maximizes gain among matched designs. Env-configurable (FPC_MATCH_K,
    FPC_MATCH_TARGET_DB); in the checkpoint signature so it forces a fresh start off the
    gain-chasing basin. Fake surrogate: S11 -9.1 dB by gen 1 (vs -1.9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
2026-07-19 Add PRS-reflectivity knobs (r1, mesh_wt) to break the match wall
    _v4 (MATCH_K=3) confirmed the match plateaus at ~-4 dB: with a fixed high-|Gamma| PRS
    the cavity Q~22 caps the match BW at ~4.5% (Bode-Fano), so the slot alone can't reach
    a -10 dB match across 9%. Give the DE control of PRS reflectivity so it can lower Q:
    r1 -- top-layer disc radius (dominant |Gamma|)
    mesh_wt -- bottom wire-mesh trace width
    Smaller/thinner -> more transmissive -> lower Q -> wider match. With the K=3 match
    penalty, the DE lowers Q just enough to hit -10 dB then maximizes gain within that --
    i.e. it finds the optimal gain-vs-bandwidth point automatically (11 knobs total).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
2026-07-21 Dashboard: show per-worker eval progress (ring-down %)
    Parses each openems_logs/worker_*.log for the latest timestep + energy-decay dB and
    shows a progress bar per active worker (% toward the -30 dB EndCriteria / NRTS cap),
    so you can see how close a generation is to landing. Only logs touched in the last
    180s count as active. FPC_DASH_NRTS overrides the cap (default 150000).
2026-07-23 Make r1 (PRS reflectivity) bounds env-overridable (FPC_R1_LO/HI)
    The free K=8 search collapses to r1=10.5 (max reflectivity / high Q) by gen 4 and never
    tests the low-Q regime, so it can't tell us whether opening the PRS improves the match.
    FPC_R1_HI=6.5 clamps the PRS transmissive (forced low Q) to test the hypothesis directly:
    if the best achievable worst-in-band S11 improves, Q is the lever; if it also plateaus at
    ~-4 dB, the match is feed-limited, not Q-limited.
2026-07-24 Update build defaults to current 11-knob DE best (worst-in-band S11 -4.42)
    From the Mumbai NP=64 run (576 evals, 2d8h): h_cav=51, h3=49, rcm_gap=7.5, y0=8.2,
    L=27.4, W=30.8, slot=13/21/2, r1=10.5, mesh_wt=1.5. Still converging (worst-in-band
    was -2.8 -> -3.2 -> -4.04 -> -4.42 over the run); this is a live snapshot to keep the
    warm-start seed current, not the final matched design.
2026-07-24 Add rcm_s (inter-tile gap) as a DE knob (12 total)
    The inter-tile gap on the RCM was frozen at P_RCM-rcm_s = 2 mm (rcm_s was fixed). Make
    rcm_s a knob (33-42.5 mm -> inter-tile gap 0.5-10 mm) so the DE can tune the gap between
    the big tiles, distinct from rcm_gap (the gap between sub-squares inside a tile). Tiles
    stay on the fixed 43 mm grid, aperture unchanged; sub-squares scale with the footprint.
    Removed rcm_s from the fixed_mm report since it is now optimized.
2026-07-24 Fix: slot knobs now seed from build defaults (p1.slot_*), not hardcoded
    The slot PARAMS defaults were hardcoded (8/10/3) instead of reading p1.slot_len/w/x,
    so a fresh warm-start reset the slot to 8/10/3 instead of seeding from the build's
    current-best (13/21/2). Now all 12 knobs seed from the build defaults, so a fresh
    run's pop[0] is exactly the current best design.
